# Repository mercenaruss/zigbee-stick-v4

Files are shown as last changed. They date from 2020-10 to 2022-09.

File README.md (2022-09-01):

# ZigStar Stick and Shield [ZIG-STAR.COM](https://zig-star.com)

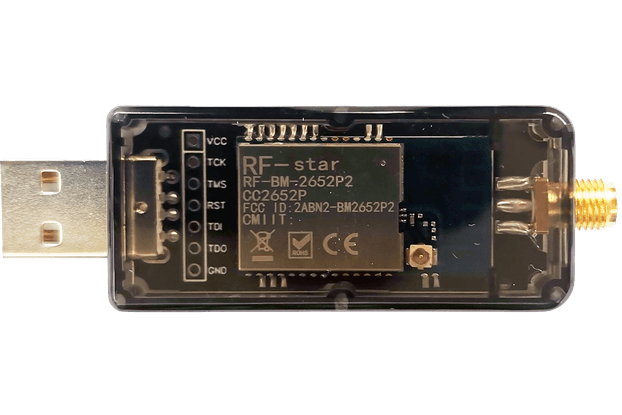
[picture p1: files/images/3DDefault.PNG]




## Features:

- [TI CC2652P](https://www.ti.com/product/CC2652P) SimpleLink™ 2.4 GHz Multiprotocol Wireless MCU targeting Zigbee,Bluetooth 5.1 Low Energy,Thread + 19.5-dBm high-power amplifier
- Support RF-BM-2652P1 and RF-BM-2652P2 Module from RF-STAR,with CC2652P on board
- BSL,RST Buttons
- 2 LED for indication
- Compatible with [Z2M](https://www.zigbee2mqtt.io/) and [ZHA](https://www.home-assistant.io/integrations/zha)
- SMA antenna port for an external antenna
- Self-programming via the [cc2538-bsl](https://github.com/JelmerT/cc2538-bsl).No external programmer needed! Push BSL button to trigger this mode.
- Communicates via the common CH340E/CH340C USB-UART Bridge

For all documentation,description and instructions visit: [ZIG-STAR.COM](https://zig-star.com)

Web-site is filled gradually.

## Contact 
For general enquiries, suggestions and errors spotted: Email me at support@zig-star.com or write me directly in [Telegram](https://t.me/mercenaruss). Community contributions to this page are very much encouraged so you could also send pull requests with your proposed changes.

### License
zigbee-stick-v4 is designed by DarthPCB's / Grecu Radu and licensed under the [Solderpad Hardware License v2.1](http://solderpad.org/licenses/SHL-2.1/).

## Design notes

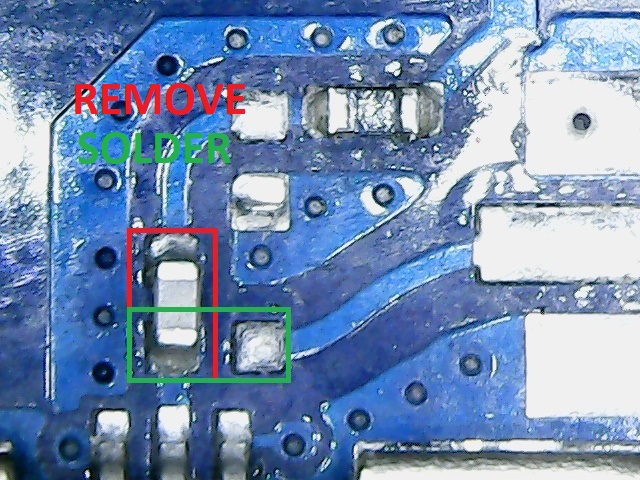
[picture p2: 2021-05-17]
files/images/Resistor-Swap.jpg

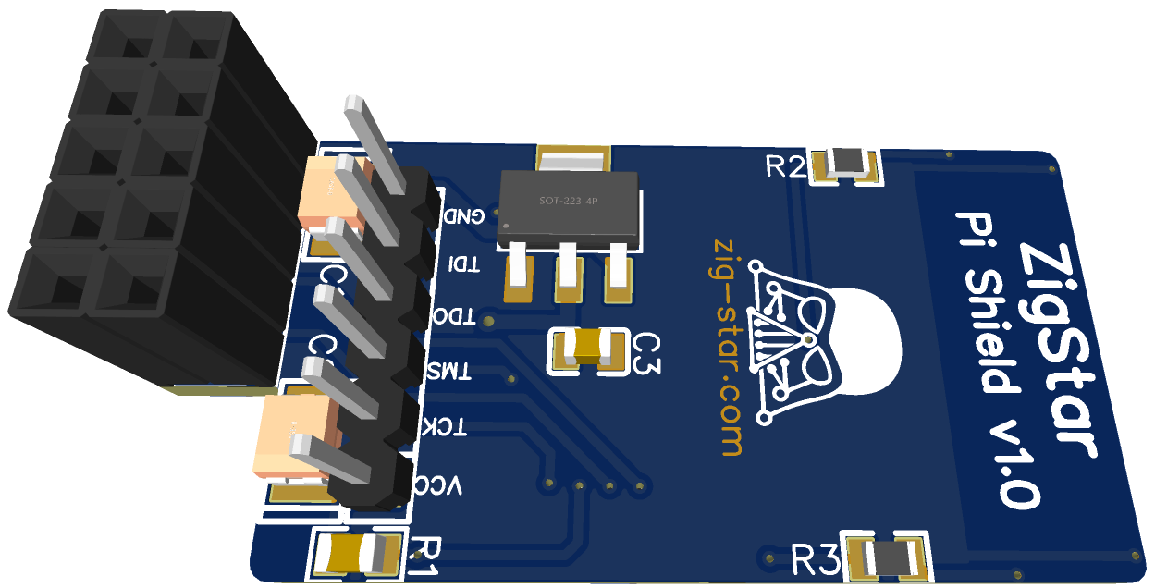
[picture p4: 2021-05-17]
files/images/zigbe_shield/3D-Bottom-Shield.png

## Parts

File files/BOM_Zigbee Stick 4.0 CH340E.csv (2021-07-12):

ID | Name | Designator | Footprint | Quantity | Manufacturer Part | Manufacturer | Supplier | Supplier Part | Price | Pins | 3DModel | JLCPCB Part Class | LCSC Assembly | Contributor | JLCPCB Part Class | SMT Type | description | link
1 | 100 | R4 | R0805 | 1 | 0805W8F1000T5E | UniOhm | LCSC | C17408 | 0.0029 | 2 | R0805_L2.0-W1.3-H0.6 | Basic Part |  | layout |  |  |  | https://item.szlcsc.com/142685.html
2 | 10uF | C1 | CAP-SMD_L3.2-W1.6-R-RD | 1 | TAJA106K016RNJ | AVX | LCSC | C7171 | 0.1833 | 2 | CASE-A_L3.2-W1.6-H1.6 | Basic Part |  | 官方封装库 |  |  |  | https://item.szlcsc.com/210648.html
3 | 100nF | C2,C4 | C0805 | 2 | CC0805KRX7R9BB104 | YAGEO | LCSC | C49678 | 0.0065 | 2 | C0805_L2.0-W1.3-H1.3 | Basic Part |  | LCSC |  |  |  | https://item.szlcsc.com/373011.html
4 | R | L1 | LED0805-RD | 1 | FC-2012HRK-620D | NATIONSTAR | LCSC | C84256 | 0.013 | 2 | LED0805_Green | Basic Part |  | layout | Basic Part |  |  | https://item.szlcsc.com/255094.html
5 | G | L2 | LED0805-RD | 1 | 0805G (Green) | KENTO | LCSC | C2297 | 0.0181 | 2 | LED0805_Green | Basic Part |  | layout | Basic Part |  |  | https://item.szlcsc.com/255094.html
6 | 10K | R1 | R0805 | 1 | 0805W8F1002T5E | UniOhm | LCSC | C17414 | 0.0027 | 2 | R0805_L2.0-W1.3-H0.6 | Basic Part |  | layout |  |  |  | https://item.szlcsc.com/142685.html
7 | 1K | R3,R2 | R0805 | 2 | 0805W8F1001T5E | UniOhm | LCSC | C17513 | 0.0028 | 2 | R0805_L2.0-W1.3-H0.6 | Basic Part |  | layout |  |  |  | https://item.szlcsc.com/142685.html
8 | DEBUG | JTAG | HDR-TH_6P-P2.54-V-M | 1 | PZ254V-11-06P | XFCN | LCSC | C492405 | 0.04 | 6 | HDR-TH_6P-P2.54-M-LI-1X6P |  |  | LCSC |  |  |  | https://item.szlcsc.com/502961.html
9 | USB-05 | USB2 | USB-A-TH_48037-0001 | 1 | USB-05 | SOFNG | LCSC | C112454 | 0.0905 | 6 | USB-A-TH_48037-0001 | Extended Part |  | LCSC |  |  |  | https://item.szlcsc.com/147771.html
10 | RF-BM-2652P1-V2 | U1 | RF-BM-2652P1-V2 | 1 |  | RF-STAR | RF-STAR |  |  | 14 |  |  |  | Radu G.
11 | AMS1117-3.3 | U2 | SOT-223_L6.5-W3.5-P2.30-LS7.0-BR | 1 | AMS1117-3.3 | SK | LCSC | C165482 | 0.0594 | 4 |  |  | Yes | LCSC |  | Extend
12 | CH340E | U3 | MSOP-10_L3.0-W3.0-P0.50-LS5.0-BL | 1 | CH340E | WCH | LCSC | C99652 | 0.6673 | 10 |  |  | Yes |  |  | Extend
13 | SMA_EDGE | ANT | SMA-EDGE | 1 |  |  |  |  |  | 5 | SMA-EDGE-CONNECTOR COPY |  |  | Pinoccio |  |  | SMA Antenna Connector
14 | 22uF | C3 | CAP-SMD_L3.2-W1.6-R-RD | 1 | TAJA226K010RNJ | AVX | LCSC | C11366 | 0.1558 | 2 |  |  | Yes |  |  | Extend
15 | SW1 | BSL | SW-SMD_L3.9-W3.0-P4.45 | 1 | SKRKAEE020 | ALPS | LCSC | C115357 | 0.1091 | 2
16 | SW2 | RST | SW-SMD_L3.9-W3.0-P4.45 | 1 | SKRKAEE020 | ALPS | LCSC | C115357 | 0.1091 | 2

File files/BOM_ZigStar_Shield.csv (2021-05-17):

ID | Name | Designator | Footprint | Quantity | Manufacturer Part | Manufacturer | Supplier | Supplier Part | Price | JLCPCB Part Class | LCSC Assembly
1 | AMS1117-3.3 | AMS117 | SOT-223_L6.5-W3.5-P2.30-LS7.0-BR | 1 | AMS1117-3.3 | SK | LCSC | C165482 | 0.0495 |  | Yes
2 | SW1 | BSL | SW-SMD_L3.9-W3.0-P4.45 | 1 | SKRKAEE020 | ALPS | LCSC | C115357 | 0.1061
3 | 10uF | C1 | CAP-SMD_L3.5-W2.8-R-RD | 1 | T491B106K016AT | KEMET | LCSC | C110050 | 0.1435 | Extended Part
4 | 22uF | C2 | CAP-SMD_L3.5-W2.8-R-RD | 1 | TAJB226K020RNJ | AVX | LCSC | C7199 | 0.2283 | Extended Part
5 | 100nF | C3 | C0805 | 1 | CC0805KRX7R9BB104 | YAGEO | LCSC | C49678 | 0.0053 | Basic Part
6 | PI Board | H1 | HDR-TH_10P-P2.54-V-R2-C5-S2.54 | 1 | Female header2.54mm2*5p Straight | ReliaPro | LCSC | C30419 | 0.049406
7 | DEBUG | JTAG1 | HDR-TH_6P-P2.54-V-M | 1 | PZ254V-11-06P | XFCN | LCSC | C492405 | 0.026519
8 | G | L1 | LED0805-R-RD | 1 | TJ-S2012SW8TGLC2G-A5 | TOGIALED | LCSC | C192318 | 0.0175
9 | R | L2 | LED0805-R-RD | 1 | TJ-S2012SW8TGLC2G-A5 | TOGIALED | LCSC | C192319 | 0.0286
10 | 10K | R1 | C0805_3D | 1 | 1206W4J0103T5E | UniOhm | LCSC | C1489 | 0.0027
11 | 1K | R2,R3 | R0805 | 2 | RS-05K1001FT | FH | LCSC | C115316 | 0.0025
12 | SW2 | RST | SW-SMD_L3.9-W3.0-P4.45 | 1 | SKRKAEE020 | ALPS | LCSC | C115357 | 0.1061
13 | RF-BM-2652P1-V2 | U1 | RF-BM-2652P1-V2 | 1 |  | RF-STAR | RF-STAR

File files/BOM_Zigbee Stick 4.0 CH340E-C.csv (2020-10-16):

ID | Name | Designator | Footprint | Quantity | Manufacturer Part | Manufacturer | Supplier | Supplier Part | LCSC Assembly
1 | USB-A-A/M Stick plate bent legs VinylPBT With a column | USB1 | USB-A-SMD_USB-A-1-TH | 1 | A/M Stick plate bent legs VinylPBT With a column | ValuePro | LCSC | C46394
2 | DEBUG | JTAG | SDIP-D-7_2.54 | 1 | MTP125-1108S1 | MINTRON | LCSC | C358689
3 | SMA_EDGE | ANT | SMA-EDGE | 1
4 | CH340C | U3 | SOP-16_L10.0-W3.9-P1.27-LS6.0-BL | 1 | CH340C | WCH | LCSC | C84681 | Yes
5 | 100 | R4 | R0805 | 1 | RK73B2ATTD101J | KOA | LCSC | C159910
6 | 10uF | C1 | CAP-SMD_L3.2-W1.6-R-RD | 1 | TAJA106K010RNJ | AVX | LCSC | C7177 | Yes
7 | 10K | R1 | C0805_3D | 1 | 1206W4J0103T5E | UniOhm | LCSC | C1489
8 | 1K | R3,R2 | R0805 | 2 | RS-05K1001FT | FH | LCSC | C115316
9 | 100nF | C2,C4 | C0805 | 2 | CT41G-0805-2X1-50V-0.1uF-K(N) | TORCH | LCSC | C126469
10 | USBLC6-2SC6 | D1 | SOT-23-6_L2.9-W1.6-P0.95-LS2.8-BR | 1 | USBLC6-2SC6 | STMicroelectronics | LCSC | C7519 | Yes
11 | AMS1117-3.3 | U2 | SOT-223_L6.5-W3.5-P2.30-LS7.0-BR | 1 | AMS1117-3.3 | SK | LCSC | C165482 | Yes
12 | 22uF | C3 | CAP-SMD_L3.2-W1.6-R-RD | 1 | TAJA226K010RNJ | AVX | LCSC | C11366 | Yes
13 | RF-BM-2652P1-V2 | U1 | RF-BM-2652P1-V2 | 1 | RF-BM-2652P1 | RF-STAR | RF STAR
14 | SW2 | RST | SW-SMD_L3.9-W3.0-P4.45 | 1 | SKRKAEE020 | ALPS | LCSC | C115357
15 | SW1 | BSL | SW-SMD_L3.9-W3.0-P4.45 | 1 | SKRKAEE020 | ALPS | LCSC | C115357
16 | TJ-S2012SW8TGLC2G-A5 | L2 | LED0805-R-RD | 1 | TJ-S2012SW8TGLC2G-A5 | TOGIALED | LCSC | C192319
17 | TJ-S2012SW8TGLC2G-A5 | L1 | LED0805-R-RD | 1 | TJ-S2012SW8TGLC2G-A5 | TOGIALED | LCSC | C192318

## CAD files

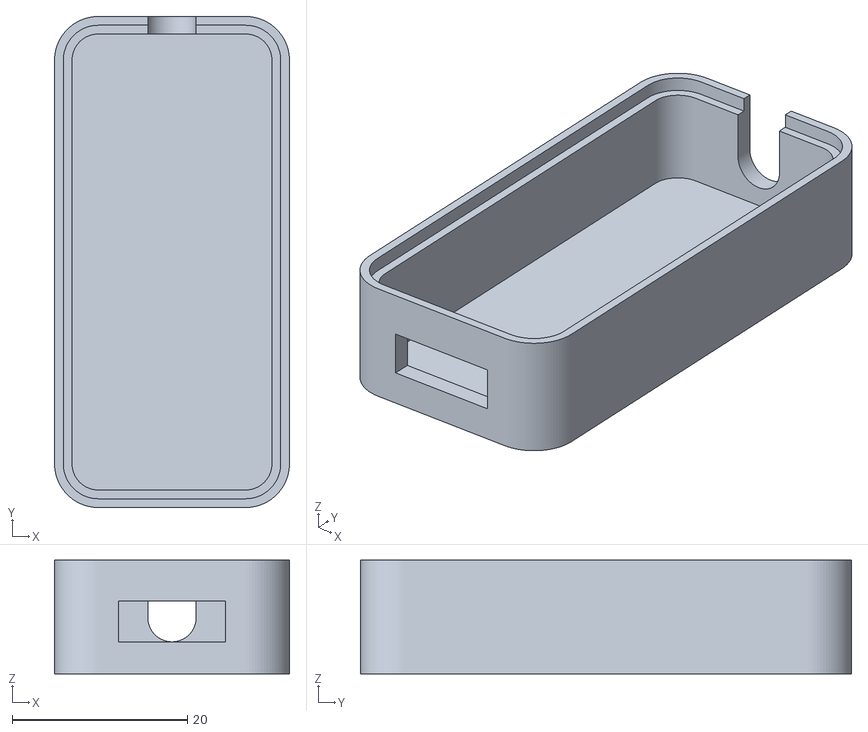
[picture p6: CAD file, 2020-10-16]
files/STL/case1-1.STL
26.8 x 56.0 x 13.0

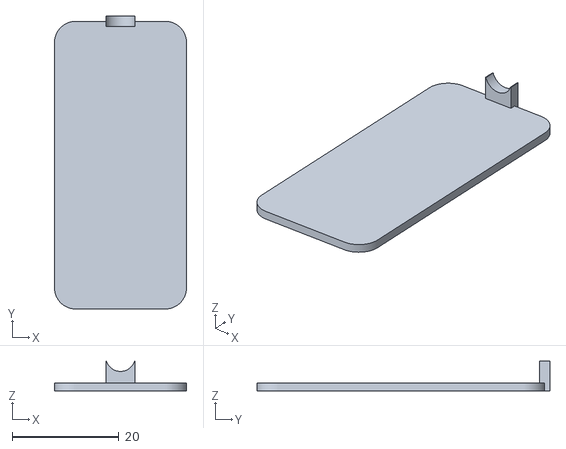
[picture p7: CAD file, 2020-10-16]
files/STL/case1-2.STL
24.8 x 55.0 x 5.58

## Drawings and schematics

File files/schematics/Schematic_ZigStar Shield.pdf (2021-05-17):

## RF-BM-2652P2

# RF-BM-2652P1/P2 MODULE,LED,BUTTONS

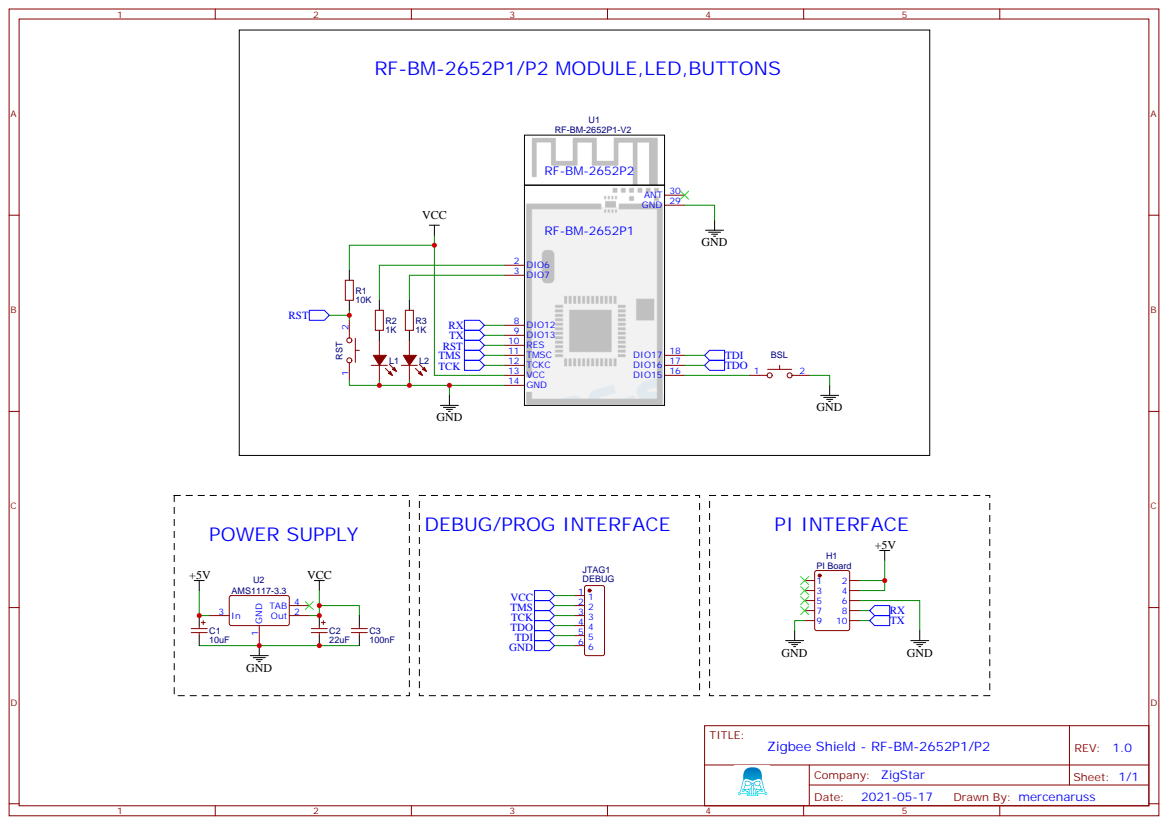
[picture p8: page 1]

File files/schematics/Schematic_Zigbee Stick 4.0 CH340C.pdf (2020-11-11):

# RF-BM-2652P1/P2 MODULE,LED,BUTTONS

## RF-BM-2652P2

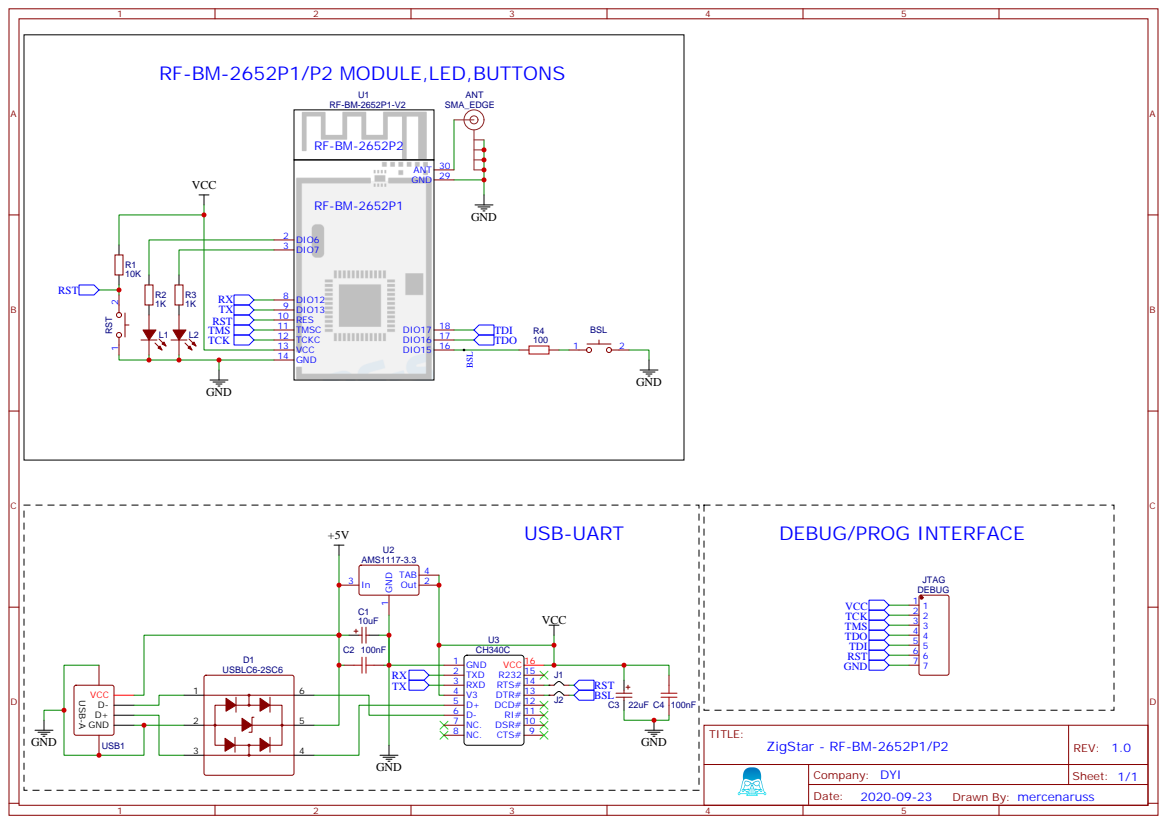
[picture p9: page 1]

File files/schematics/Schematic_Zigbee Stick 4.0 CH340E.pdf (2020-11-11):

# RF-BM-2652P1/P2 MODULE,LED,BUTTONS

## RF-BM-2652P2

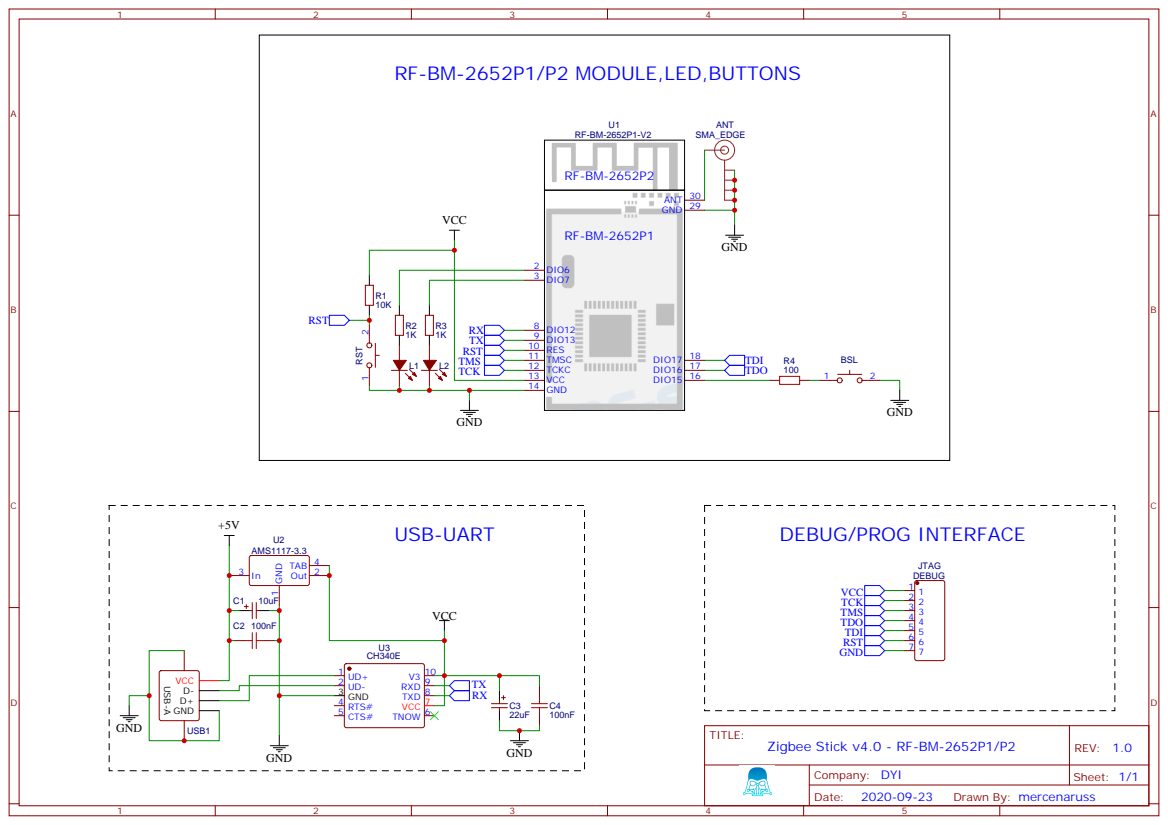
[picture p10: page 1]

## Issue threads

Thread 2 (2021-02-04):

Router problem

r312645, 2021-02-04:
I flashed [this router firmware.](https://github.com/Koenkk/Z-Stack-firmware/tree/master/router/Z-Stack_3.x.0/bin)
It works well, but how do I re-pair to other coordinator?
I pressed the reset button but nothing happened.

mercenaruss, 2021-02-04:
Please flash next firmware: https://github.com/Koenkk/Z-Stack-firmware/blob/master/router/Z-Stack_3.x.0/bin/CC1352P2_CC2652P_launchpad_router_20210128.zip

Before flash, let coordinator be in pairing mode,so when router is flashed he will search automatically to pair.

r312645, 2021-02-04:
Thanks for reply.
Does that mean I can only re-flash the firmware to re-pair ?
Can I reset router like the picture below？
![Uploading Screenshot_2021-02-04-22-40-56-55.jpg…]()

r312645, 2021-02-04:
Thanks for reply.
Does that mean I can only re-flash the firmware to re-pair ?
Can I reset router like the picture below？

Radu <notifications@github.com> 於 2021年2月4日 週四 22:33 寫道：

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

mercenaruss, 2021-02-04:
you can do it,you have 2 button on PCB,try them,i didnt install this firmware,i need to test.

r312645, 2021-02-04:
I found that the bsl button works, thank you.  I have not installed the bsl
button because I do not have 100 ohm.  Now I use 1k ohm on the bsl button,
will this cause any problems?

Radu <notifications@github.com> 於 2021年2月4日 週四 23:29 寫道：

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

mercenaruss, 2021-02-05:
> se any problems?

if button is its working then no problem.
Thank you for update.

Closed 2021-02-05.

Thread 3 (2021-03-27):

improvemt suggestion - expose serial connection to border connector

klassisch, 2021-03-27:
Thanks a lot for your great work developing this board and presenting it here.
I have a suggestion for an improvement in future releases or similar projects:
The USB port is not always the best solution for everyday operation.
Many automation systems are running on a server or computer not beeing located at the best location regarding the needs of RF wave propagation.
So, an ethernet interface is a good supplement.
This can be done using a commercially available converter such as USR-TCP232-T2 or similar.
I hand-modified your module to attach such an add-on.
Unfortunately I had to cut a trace and to make some ugly solder mods.
In future versions it would be highly appreciated if you could support such alternative signal paths by exosing the serial signals to the (extented) border connector. It could be as
* tap the connection between cc2652P module Txd to CH340 RxD and connet it to an additional connector pin
* connect the cc2652P module RxD to an additional connector pin
* connect the CH340 TxD to an additional connector pir
* connect the cc2652 RxD to the CH340 TxD by a removable link such as a jumper or a resistor which could be removed
* if possible and space left, connect the +5V to an additional connector pin

I modified your board by cuttin and adding some wires.

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

It looks ugly like this but it works.
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

I have more images and a description in the ioBroker forum (German language) https://forum.iobroker.net/post/601380 .

mercenaruss, 2021-04-11:
@klassisch Hello and thank you for kind suggestion.
We can discuss this in Telegram,so we can bring to life a new device.
Please contact me: https://t.me/mercenaruss

mercenaruss, 2021-05-15:
Following our discussion please be notified,that your wished was taken in consideration.
Work is ongoing.

Closed 2021-05-15.

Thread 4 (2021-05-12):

Low Range / Link Quality

lg-eng, 2021-05-12:
Hi there, thanks for the nice design! I bought one of them from ebay. It is working as a coordinator but unfortunately the range is very poor. max ~2m line of sight. Do you have any suggestions where to start tweaking to improve the range? Could a software update help?

Thanks!

lg-eng, 2021-05-12:
Hi again, I did some research and it appears there is a resistor missing going to the onboard antenna. I guess this is necessary to disable the onboard antenna? But how is the board connected with the external antenna? Shouldn't be there a jumper or something?
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

lg-eng, 2021-05-12:
Problem solved! Jumper in green. LQI to an OSRAM switch @ 40cm is 132 outgoing and 142 incoming. Second OSRAM Switch @ 5m and two walls (20cm bricks) 44/44. Anyone with some reference measurements?
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

lg-eng, 2021-05-12:
Thanks again for the board and of course for sharing!

mercenaruss, 2021-05-14:
Hello @lg-eng ,sorry for late answer. You are right resistor supposed to be repositioned  in order to use external antenna,just solder the resistor to match external antenna.
Will add this description on github.

lg-eng, 2021-05-15:
Ah now worries I'm glad you answered! So there should be a resistor? I just soldered a wire as a jumper because the resistor was missing entirely. Do you have, by any chance, the value of the resistor?

mercenaruss, 2021-05-15:
@lg-eng Please follow the picture.
Just make a swap according to the picture.
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

lg-eng, 2021-05-16:
Thanks for the picture, unfortunately I do not have this resistor any more. I have to replace it. Could you share the value of the resistor?

mercenaruss, 2021-05-24:
> Thanks for the picture, unfortunately I do not have this resistor any more. I have to replace it. Could you share the value of the resistor?

Sorry,is no a resistor. I cant identify.

Closed 2021-05-12.

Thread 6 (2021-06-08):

Question: can you post the CPL file?

gabr777, 2021-06-08:
Very nice project, thanks for sharing.
I'm looking at the 4.0 version of CH340E.
Could you post the CPL file that is needed for the SMT assembly through jlcpcb?

mercenaruss, 2021-06-14:
Hello, yes, i will post it soon,will be available on zig-star.com in couple of days.

lifeandfate1, 2021-06-24:
Hey just wanted to check in with the CPL file. I can't find it on zig-star.com

mercenaruss, 2021-06-26:
@gabr777 and @lifeandfate1 for which version you need CPL file? CH340E or CH340C ?

mercenaruss, 2021-06-26:
@gabr777 and @lifeandfate1 ,sorry for question,but for what is required CPL file in your case? Mass production?

lifeandfate1, 2021-06-26:
I was just wanting one and to get jlcpcb to make one for me.

mercenaruss, 2021-06-28:
@lifeandfate1 minimum quantity for JLPCB is 2 SMT and 5 PCB.
Anyways RF-Star Module is not possible to do on JLPCB,you need to buy separately.
You can find all information on [website](zig-star.com)

randarth, 2021-07-09:
Hi, first of all - thanks for great work and for sharing it!
I would also like to buy some preassembled sticks from jlcpcb. Not for mass production, but I'll need at least 4 pcs for friends and family who I managed to switch from various tuyas and ewelinks to Home Assistant. Right now we're using CC2531 sticks and ZHA and I want to migrate all of us to Zigbee2MQTT with better zigbee coordinators.
On Zigstar project website you wrote that CH340E version is "JLPBC SMT Assembly available", but looks like it's mandatory to have a file with SMD placement.
I know that they won't solder main RF-STAR module, but I think I'll manage that on my own.
Can you add this cpl file to github?

mercenaruss, 2021-07-12:
Hello everyone, @randarth @lifeandfate1 @gabr777 Pick and Place file now available in repository,please use new gerbers for CH340E version,they will match with Pick and Place.

Closed 2021-07-12.

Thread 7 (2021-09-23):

[SUGGESTIOn] Switch to USB-to-UART bridge chip with programmable EEPROM so can add custom "Product Description String" string as unique identifier?

Hedda, 2021-09-23:
Re-post idea from HA community -> https://community.home-assistant.io/t/zigstar-zigbee-coordinators-and-routers/338586/6

Please consider switching the design to an other USB-to-Serial converter chip with its own writable EEPROM as a hardware feature.

This would allow you to add your own custom "Product Description String" as a unique identifier for it via the USB interface, and the reason for wanting a unique identifier via the USB interface is in order to enable the possibility for it to support automatic USB discovery of Zigbee USB adapters.

The whole point of this is to make it possible for developers to make the initial installation of Zigbee solution plug-and-play friendly and easier for different home automation software to automatically USB discover and initiate a setup without end-user interactions.

Support for USB discovery was recently added to Home Assistant OS (formerly HASSIO) and the ZHA integration for it, see here:

https://community.home-assistant.io/t/unique-friendly-name-description-for-automatic-zigbee-usb-adapter-discovery-in-home-assistant-zha-using-dongle-vendor-product-i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

and also see pull request example for whilelisting USB devices for ZHA https://github.com/home-assistant/core/pull/56201

That unique customized USB description string could be something like ex.; "**_ZigStar USB Stick version 4 hardware revision 2.0.0_**".

The unique "description" string for each USB adapter can then be added to HA via a PR like this -> https://github.com/home-assistant/core/pull/56201

As I understand it, cheaper CH340 series (example CH340C and CH340E) by WCH which unfortunately does not support this feature.

UPDATE! It has now been confirmed that the CH340B variant does have an EEPROM that support "Product Description String", etc.

http://www.wch-ic.com/products/CH340.html

I understand that more expensive chips like FT231 chips by FTDI and CP210x chips by Silicon Labs / Silabs do support this feature:

https://ftdichip.com/products/ft231xs/
https://ftdichip.com/products/ft231xq/

FT231X/FT231XS: "**_Key Hardware Features_**" "**_Fully integrated 2048 byte EEPROM for storing device descriptors and CBUS I/O configuration._**"

https://www.silabs.com/interface/usb-bridges/classic/device.cp2102
https://www.silabs.com/interface/usb-bridges/classic/device.cp2104
https://www.silabs.com/developers/usb-to-uart-bridge-vcp-drivers
https://www.silabs.com/documents/public/data-sheets/cp2102n-datasheet.pdf
https://www.silabs.com/documents/public/application-notes/an197.pdf
https://www.silabs.com/documents/public/application-notes/an978-cp210x-usb-to-uart-api-specification.pdf
https://www.silabs.com/documents/public/application-notes/AN571.pdf

"**_The CP2102N devices have the following features_**" "**_Internal 960-byte programmable ROM for vendor ID, product ID, serial number, power descriptor, release number, and product description strings_**"

"**_The CP2102N includes an internal electrically erasable programmable read-only memory (EEPROM). This memory may be used to customize the USB Vendor ID (VID), Product ID (PID), Product Description String, Power Descriptor, Device Release Number and Device Serial Number as desired for OEM applications. If the EEPROM is not programmed with OEM data, the default configuration data shown in the table below is used._**"

"**_Product String The Product String is an optional string that describes the product. It is limited to 126 characters._**"

PS: I understand that a bonus feature in of chips like FT231 and CP210x is to add the ability to allow users to auto-reset and put the device in bootloader mode via the DTR/RTS pins exposed will enable much easier firmware upgrades for the end-users as they will no longer need to press any buttons to enter bootloader mode, and then bootloader mode could be activated via software from the firmware flasher program software which could make the OTW (Over-The-Wire) firmware upgrade procedure more user-friendly.

Hedda, 2021-10-05:
@mercenaruss I noticed this PR to Home Assistant Core which indicates that tube0013 must have managed have added USB discovery in Home Assistant and ZHA for tubeszb ch340B based serial devices by configuring a unique "Product Description String":

https://github.com/home-assistant/core/pull/56719

So the CH340B is another USB to serial bridge chip that integrates EEPROM used to configure the "Product Description String", etc.

http://www.wch-ic.com/products/CH340.html

mercenaruss, 2021-10-05:
@Hedda I used CH340B in last 2 batches, but i didn't configure PID and VID.
Will take a look at it and revert.

tube0013, 2021-10-05:
The tool to program the eeprom is hard to find. Google "ch340cfg-produce"

It's in Chinese and windows only, but pretty straight forward.

mercenaruss, 2021-10-05:
@Hedda First of all ,i should get a VID and PID

tube0013, 2021-10-05:
> @Hedda First of all ,i should get a VID and PID

I didn't want to mess with the VID and PID as it may affect the serial drivers.

HA can match solely on the descriptor or serial which is what I customized

mercenaruss, 2021-10-05:
@Hedda so descriptor is enough,hmm okay,will try this.

mercenaruss, 2021-11-11:
@Hedda I'm on my waiting submitting PR.
Thank you very much for your assistance.
Will try soon to find time for LAN Zeroconf.

Hedda, 2021-11-12:
Very nice! For reference, others can find the pull request for ZigStar USB Discovery here -> https://github.com/home-assistant/core/pull/59559

@mercenaruss You might also want to link a document update for home-assistant.io from that parent PR 😄

As noted for that, just make sure that target their "next" branch and that no other commits are in that patch:

https://github.com/home-assistant/home-assistant.io/blob/next/source/_integrations/zha.markdown

mercenaruss, 2021-11-12:
@Hedda i did a mistake on the way, now what i should do? make a new PR, because something is going wrong with rebase.

Hedda, 2021-11-12:
> @Hedda i did a mistake on the way, now what i should do? make a new PR, because something is going wrong with rebase. [home-assistant/home-assistant.io#20275](https://github.com/home-assistant/home-assistant.io/pull/20275)

Yes probably easiest to just close https://github.com/home-assistant/home-assistant.io/pull/20275 and create a new PR.

mercenaruss, 2021-11-12:
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

Can you help me with a PR on this, I messed up and really cant understand how to fix this.

Hedda, 2021-11-15:
PR submitted as you know -> https://github.com/home-assistant/home-assistant.io/pull/20320

Recommend leaving it like that and then submit a change later once your new name is established.

New issue here for name discussion so that you can close https://github.com/mercenaruss/zigbee-stick-v4/issues/7 ;) Please see  -> https://github.com/mercenaruss/zigbee-stick-v4/issues/9

mercenaruss, 2021-11-15:
@Hedda Done

Closed 2021-11-15.

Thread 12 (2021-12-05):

Request for easyEDA project files

irakhlin, 2021-12-05:
Hello,
First off just wanted to thank you for the project, recently received a zigstar4 that is currently being used a router and I am loving the range. I was hoping it would be possible for you to share the easyeda project files used to generate the gerber files. I am hoping to add a few components, specifically a temperature/humidity sensor and potentially a light sensor. I have no plans to mass produce any result  as it would be simply a hobby project. The easyEDA project files would give me some starting points in designing the PCB.

Please let me know if this is possible.

mercenaruss, 2022-09-06:
Unfortunately i cant provide this.
But i'm very open for improvements,if you have any in mind you can drop me an email on support@zig-star.com

Closed 2022-09-06.

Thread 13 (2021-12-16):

Test and verify Koenkk experimental firmware for CC2652P configurable up to 20 dBm TX power output

Hedda, 2021-12-16:
FYI, Koenkk has now uploaded an experimental firmware for CC2652P/CC1352P with a default set to 9 dBm (and a max of 20 dBm):

https://github.com/Koenkk/Z-Stack-firmware/issues/323

He mentions in https://github.com/Koenkk/zigbee2mqtt/issues/8885 that he does not have RF measurement equipment so cannot confirm RF output power.

Would be great if you can test and verify Koenkk experimental firmware for CC2652P configurable up to 20 dBm TX power output.

Hedda, 2021-12-20:
FYI, Koenkk has now released mentioned +20 dBM RF power output enabled version as "Z-Stack_3.x.0 20211217" in the develop branch and closed issues as confirmed working with improved LQI as result:

[https://github.com/Koenkk/Z-Stack-firmware/tree/develop/coordinator/Z-Stack_3.x.0/bin](https://github.com/Koenkk/Z-Stack-firmware/tree/develop/coordinator/Z-Stack_3.x.0/bin)

[https://github.com/Koenkk/Z-Stack-firmware/issues/323](https://github.com/Koenkk/Z-Stack-firmware/issues/323)

[https://github.com/Koenkk/zigbee2mqtt/issues/8885](https://github.com/Koenkk/zigbee2mqtt/issues/8885)

That firmware has during the weekend been confirmed working by several community members with up to +20 dBM RF power output enabled, (tested in both Zigbee2MQTT and ZHA), and according to Koenkk it has also been confirmed working by ITead's own Sonoff Zigbee engineer using RF analyzer as well, so I think later if and when proven stable we can expect this version to ship with future batches.

Note that any releases in the develop branch should still be considered experimental until proven stable and any bugs specifically verified related to this firmware version should be reported as new issues to:

[https://github.com/Koenkk/Z-Stack-firmware/issues](https://github.com/Koenkk/Z-Stack-firmware/issues)

Sillyjan, 2021-12-29:
@Hedda i did a small test with my zigstar stick.
after updating to the experimental firmware non of my zigbee devices worked. After reverting back to the stable version everything was fine.

Not yet sure if I did something wrong or not, but will do some more testing to make sure.

Hedda, 2022-01-12:
@mercenaruss FYI, 20211217 has now also been moved to "master" branch and should be considered stable as recommended version:

https://github.com/Koenkk/Z-Stack-firmware/tree/master/coordinator/Z-Stack_3.x.0/bin

By the way, the new "develop" branch got another also bug-fix:

https://github.com/Koenkk/Z-Stack-firmware/tree/develop/coordinator/Z-Stack_3.x.0/bin

https://github.com/Koenkk/Z-Stack-firmware/blob/develop/coordinator/Z-Stack_3.x.0/CHANGELOG.md

Closed 2022-09-01.

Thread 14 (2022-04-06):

How to flash Zigstar Shield using python

hacor, 2022-04-06:
Hello!

Forgive me this newbie question, but I was wondering if you could guide me in how to flash the Z2M firmware onto my Zigstar shield. I will be using the [z-stack firmware](https://github.com/Koenkk/Z-Stack-firmware/tree/master/coordinator/Z-Stack_3.x.0/bin) as suggested on the Zigstar Shield page.

I was wondering on how to enable the programming mode. Because with the USB stick it is clear you need to push the BSL button when plugging it in, but not sure how to get there with the shield.
I was hoping to be able to program the device using the python `cc2538-bsl.py` script from the raspberry pi itself without the need of an external programmer. Perhaps I was to optimistic :-)

Warm regards

Hacor

mercenaruss, 2022-04-20:
@hacor Hi,this is possible to do. A little work arounf is required. Give some time to check and revert.

mercenaruss, 2022-09-06:
I dig in this:
1. Shield can be programmed using cc2538-bsl.py
2. You need to press RST and BSL simultaneously and release RST in the same time holding BSL then runn script for update.

You are done!

hacor, 2022-09-06:
@mercenaruss Fantastic! Thank you.
Closing this issue

Closed 2022-09-06.

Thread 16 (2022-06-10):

[REQUEST] OpenThread Border Router (OTBR) RCP and NCP firmware images for CC2652R based ZigStar Stick and Shield adapters?

Hedda, 2022-06-10:
@mercenaruss  Can you please consider providing OpenThread Border Router (OTBR)  "RCP mode" firmware imagesas well as "NCP mode" firmware images (with support for the OpenThread `spinel+hdlc+uart` protocol) and preferably using the latest SDK for this Texas Instruments CC2652 based adapter so that it will be compatible with the "OpenThread Border Router Add-on" that Home Assistant developer agners (Nabu Casa employee Stefan Agner) is currently developing? Check out:

https://github.com/home-assistant/addons-development/tree/master/openthread_border_router

https://github.com/openthread/ot-br-posix/

https://github.com/agners

https://community.home-assistant.io/u/agners/summary

https://groups.google.com/g/openthread-users/

 OTBR should be a "Thread Certified Component" Texas Instruments CC2652 based chips:

https://github.com/openthread/ot-cc13x2-cc26x2/blob/main/src/cc2652/README.md

https://github.com/openthread/ot-cc13x2-cc26x2

https://github.com/openthread/openthread/tree/main/examples/platforms

https://dev.ti.com/tirex/explore/node?node=APzU0zOtgnQIe0sFnHCfxg__BSEc4rl__LATEST

https://openthread.io/vendors/texas-instruments

https://www.threadgroup.org/What-is-Thread/Thread-Benefits#certifiedproducts

https://training.ti.com/thread-cc2652-cc1352

The main reason for this request is that an "RPC" firmware with OTBR (OpenThread Border Router) support will make your adapter will be compatible with upcoming Thread based "Matter" (Project CHIP / Connected Home over IP) devices if used in Home Assistant with their other add-ons for the that is also in development. This addon by agners requires that the radio hard a firmware in "RPC" mode instead of the no traditional "NCP" mode:

https://github.com/home-assistant/addons-development/tree/master/chip_controller_repl

https://github.com/home-assistant/addons-development/tree/master/chip_tool

https://github.com/project-chip/connectedhomeip

https://buildwithmatter.com

https://csa-iot.org/all-solutions/matter/

Also having optional OpenThread "NCP" border router firmware would allow users to alternatively use other existing OpenThread applications that use "NCP" mode instead of the newer "RPC" mode which require additional component running on the host. Ex:

https://github.com/openthread/wpantund

Note that so far agners has only worked with Silicon Labs based adapter with OpenThread "RPC" firmware for Thread based Matter (as well as ESP32-C3 based devkit for Matter over WiFi) and that is only because it is a Silabs EFR32MG21 chip based adapter that will ship inside the official Home Assistant Yellow (formerly Home Assistant Amber) hardware:

https://github.com/zigpy/zigpy/discussions/894

https://github.com/home-assistant/addons-development/tree/master/silabs-multiprotocol

https://www.home-assistant.io/blog/2021/09/13/home-assistant-yellow/

https://www.crowdsupply.com/nabu-casa/home-assistant-yellow

PS: By the way, you might be interested in the the "Matter" workshop that Home Assistant is holding on the 15th of June even if they are in that specific workshop will not use a Thread based controller or devices and instead use a WiFi (+ Bluetooth) based "Matter" devices:

https://www.home-assistant.io/blog/2022/05/29/matter-in-home-assistant-workshop-announcement/

https://www.youtube.com/watch?v=9fOHBl5w0_k

https://community.home-assistant.io/t/matter-in-home-assistant-workshop-announcement/426129/

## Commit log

2020-10-30 Update Gerber
    Update gerbers with name for stick
2020-11-10 Update Gerber
    Update Gerber accordign LaunchPad P-2
2020-11-11 Update images of PCB's
    Update images of PCB's with new changes
2021-05-17 Zigbee Shield PCB added
2021-05-17 Shield Boom Added
    [BOM_ZigStar_Shield.csv]
2021-05-24 Create Gerber_ZigStar - VG-S48_AK-N-12.zip
2021-05-24 Add new PCB with factory case
    VG-S48/AK-N-12
2021-07-12 Update Gerber and add pick&place
    Updated Gerber for CH340E and added Pick and Palce file for SMT Assembly
    [BOM_Zigbee Stick 4.0 CH340E.csv, PickAndPlace_Zigbee Stick 4.0 CH340E.csv]
2021-07-12 Update Pick and Place
    [PickAndPlace_Zigbee Stick 4.0 CH340E.csv]
2021-07-12 Version Control
    Now each gerber have a version
2021-07-16 Update Gerber_Zigbee Stick v4.0 - CH340C - Factory VG-S48_AK-N-12.zip
    Change from 7 to 6 PIN JTAG
2021-07-17 Update Gerber_Zigbee Stick v4.0 - CH340C - Factory VG-S48_AK-N-12.zip
2021-10-05 Create LICENSE
    Solderpad Hardware License v2.1
